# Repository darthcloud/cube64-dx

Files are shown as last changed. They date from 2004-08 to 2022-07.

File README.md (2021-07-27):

See my new project:\
BlueRetro - Multiplayer Bluetooth controllers adapter for retro video game consoles\
<https://hackaday.io/project/170365-blueretro>\
<https://github.com/darthcloud/BlueRetro>

# Cube64

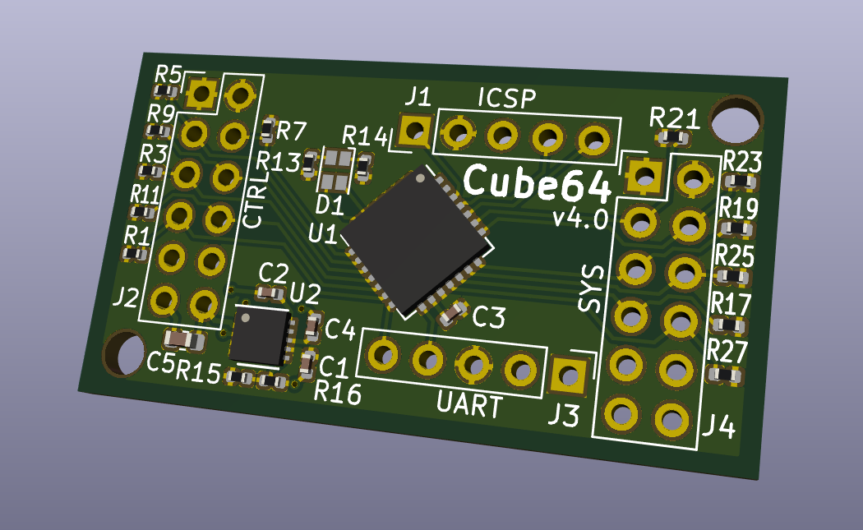
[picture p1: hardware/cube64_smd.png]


## Introduction
This is a project to build an adaptor for using GameCube controllers
with N64 consoles. The motivation behind this is that the N64 has some
really great games, but the controller hardware is rather bad- the
joysticks wear out quickly, and the layout is odd. The GameCube
controllers, however, have a superset of the features and a much
better joystick.

A secondary goal of this project is to more thoroughly reverse engineer
the protocols involved and create reusable libraries for interfacing PIC
microcontrollers to N64 and GameCube devices. The very basics of reverse
engineering the two protocols were done before Micah (@scanlime) started this project,
but she quickly discovered that there's much more to the protocol. We believe
this project may be the first one to completely reverse engineer the
protocol used by standard N64 controllers, including peripherals like the
Controller and Rumble Paks.

All code here is released under the GPL. This means that if you have basic
electronics skills and a way to program the microcontroller, you can build
your own cube64 adaptor easily. The hardware is extremely simple, and all
the complexity of reverse engineering and writing code is done for you ;)

## Discussion

https://github.com/darthcloud/cube64-dx/discussions

## Usage

The completed adaptor plugs into an N64 console, and a regular GameCube
controller or WaveBird receiver plugs into the adaptor.
The default button mapping is as follows:

GameCube | N64
-------- | ---
 | 
 | 
 | 
 | 
 | 
 | 
 | 
 | 
 | 
 | 
 | 

By default the adaptor layout banks are loaded with the first four preset.
See [wiki](https://github.com/darthcloud/cube64-dx/wiki) for more information on the preset.

### Main menu

All the configurable feature of the adaptor can be accessed thought this menu.
To access the menu:

   1. Hold down the analog L and R buttons down most of the way, but not enough to
      push the end-stop buttons, and press Start.

The adaptor LED will be ON as long you are inside the menu.

Once in the menu the N64 will receive blank status packet regardless of buttons
pressed on the GameCube controller. An invalid selection in the menu will exit
the menu.

### Menu options

#### Axis & Button remapping

The button mapping is stored in non-volatile memory, and may be modified during
gameplay. To change the mapping for one button or axis direction:

  1. While in the main menu, press Start again.

  2. If you have the rumble power connected, you should feel a brief rumble.

  3. Press the button you wish to remap. This includes any button or axis direction.

  4. Press the button you want to map it to. This button is always interpreted
     according to the table below.

  5. If the mapping was successful and you have rumble power connected, you should feel
     a brief rumble.

GameCube | N64
-------- | ---
 | 
 | 
 | 
 | 
 | 
 | 
 | 
 | 
 | 
 | 
 | 

#### Special function

It's possible to map a special function to a button instead of a N64 button.

  1. While in the main menu, press Y.

  2. If you have the rumble power connected, you should feel a brief rumble.

  3. Press the button you wish to set the function to.

  4. If you have the rumble power connected, you should feel a brief rumble.

  5. Press the button corresponding to the special function you want. This button is always
     interpreted according to the defaults below.

  6. If the mapping was successful and you have rumble power connected, you should feel
     a brief rumble.

##### Function available:

GameCube | Function
-------- | --------
 | Temporary overwrite current mapping layout <br/>with layout corresponding to the D-pad <br/>direction until button is released.
 | A+C-Down two buttons mapping.
 | B+C-Right two buttons mapping.
 | Turbo disable (Default).
 | Faster turbo.
 | Medium turbo.
 | Slower turbo.

#### Mapping analog trigger axes

By default button remapping and special function will only map to the digital trigger buttons.
Pressing X before either menu options will allow mapping to the analog trigger axes.

  1. While in the main menu, press X.

  2. If you have the rumble power connected, you should feel a brief rumble.

  3. Press either Start or Y. See *Axis & Button remapping* or *Special function* sections for next steps.

#### Mapping layout reset

To reset the current active mapping layout to the above defaults:

  1. While in the main menu, press Z.

  2. If you have the rumble power connected and the reset was successful, you should
     feel a brief rumble.

#### Adaptor accessory mode

The adaptor can either emulate a Rumble Pak, let all controller slot command
bypass to a real N64 controller or display the slot as empty.
To switch between the modes:

  1. While in the main menu, press D-pad UP.

  2. If you have the rumble power connected, you should feel a brief rumble.

  3. Press D-pad UP for bypass mode, D-pad LEFT for Rumble Pak mode or D-pad RIGHT
     for emptied slot controller.

  4. If you have the rumble power connected and the mode change was successful, you should
     feel a brief rumble.

This setting is volatile. Adaptor always starts with Rumble Pak mode.

Empty mode is useful for some game that report error with a Rumble Pak.
For those games, without even invoking the main menu you may simply hold D-pad RIGHT
on power on to disable the Rumble Pak mode and avoid the error.

Holding D-pad UP at boot will set bypass mode as well.

Setting bypass mode while no N64 controller is present in the secondary adaptor port will make
the adaptor reset.

#### Mapping layout selection

It is possible to save up to 4 sets of mapping layouts so you can easily use different keys
mapping in different games. To change between the layout does the following:

  1. While in the main menu, press D-pad LEFT.

  2. If you have the rumble power connected, you should feel a brief rumble.

  3. Press one of the 4 D-pad directions which correspond to the 4 layout available.

  4. If you have the rumble power connected and the layout change was successful, you should
     feel a brief rumble.

All layout by default hold the default button configuration. Just select one of 4
layouts and then change the button configuration using the button mapping key combo
described above.

When you select a layout, it is saved into the EEPROM so the next time you power up
the adaptor the last used will be reloaded automatically.

#### GameCube joysticks config

By default the joysticks value from the GameCube controller are scale to match the N64
joystick value range. This can be disabled to use the GameCube range instead (< v3.1 behavior).
A response curve can also be applied to a GC axis. By default none is applied (Linear).
Scale and curve setting are save independently for each axis and each layout.

  1. While in the main menu, press D-pad RIGHT.

  2. If you have the rumble power connected, you should feel a brief rumble.

  3. Press either direction on one of the four GC joystick axes.

  4. If you have the rumble power connected, you should feel a brief rumble.

  5. Press X to enable or Y to disable the scaling function.
     Or press one of the D-pad directions for enabling a response curve.
     (UP: Aggressive, LEFT: Relaxed, RIGHT: Wide, DOWN: S-Curve)
     Or press A for no response curve (Linear).

  6. If you have the rumble power connected and the layout change was successful, you should
     feel a brief rumble.

This option is saved into the EEPROM so the next time you power up the adaptor the last
used setting will be reloaded automatically.

#### Preconfigured button mapping layout

Eight pre-defined button mapping layout can be loaded in the currently active layout.
See [wiki](https://github.com/darthcloud/cube64-dx/wiki) for preset detail.

  1. While in the main menu, press D-pad DOWN.

  2. If you have the rumble power connected, you should feel a brief rumble.

  3. Press any direction on GC D-pad or main joystick to choose one preset.

  4. If you have the rumble power connected, you should feel a brief rumble.

### Calibration

The adaptor handles calibration in almost the exact same way a GameCube does. If
your joystick is drifting or unresponsive during gameplay, you should be able to
recalibrate it by performing any of the following actions without touching the
joystick, C-stick, L button, or R button:

  1. Hold down X, Y, and Start for a couple seconds during gameplay.

  2. Unplug the controller from the adaptor and plug it back in.

  3. Unplug the adaptor from the N64 and plug it back in.

  4. Turn off the N64 then turn it back on. (The reset button won't
     recalibrate, since the adaptor doesn't lose power or get reinitialized)

### 1 player 2 controllers control style

If connected to two ports of the system, the adaptor will answer automatically
a limited button status and identity commands on the 2nd port. This allows
to play GoldenEye 007 and Perfect Dark using their respective 1 player 2 controller
control style.

Analog input map for the 1st controller C Buttons will map to the 2nd controller joystick.
Digital input map for the 1st controller R button will map to the 2nd controller Z button.

## Hardware

There are currently two versions of the Cube64 hardware:

  - The "Cube64 DIY" uses a PIC18F14K22 microcontroller. Just about any
    electronics hobbyist should be able to build it easily. 5V can be
    provided either externally or by using a charge pump in 8-pin SOIC
    package.

  - The "Cube64 SMD" uses a PIC18F24Q10 microcontroller, and a
    charge pump in 10-pin DFN package. PCB gerber and KiCad sources
    are provided.

Both versions of the hardware have the same button remapping features
and responsiveness, as the only difference in their firmware is a few lines
worth of compile-time configuration. The DIP version of the Q10 could also
be used for the DIY version, but the package is bigger.

## Status

The protocol used between the N64 and controller, and between the controller
and Controller Pak is well understood now. An RS-232 to N64 bridge and several
Python programs demonstrate just about all of the protocol.

The necessary subset of the protocol has been implemented in the Cube64
firmware to emulate an official N64 controller with Rumble Pak. If 5V power
for the motor can be supplied to the GameCube controller, its rumble motor
will be used to emulate the N64 Rumble Pak.

It should be possible to emulate the N64 Controller Pak using the results of the
reverse engineering.

## Contents

##### firmware
Source code for the firmware, in PIC assembly. It was developed
using the open source "gputils" package (use latest [snapshot](https://sourceforge.net/projects/gputils/files/snapshot_builds/src/)). The firmware for
the adaptor itself is "cube64.asm", but there are a few additional
test programs and libraries.

##### hardware
This includes schematics and PCB for the adaptor, in KiCad source format.

##### notes
Utilities and documentation produced while reverse engineering.

## Authors
* **Micah Elizabeth Scott** - *Initial version* - [scanlime](https://github.com/scanlime)
* **Jacques Gagnon** - *Newer stuff* - [DarthCloud](https://github.com/darthcloud)

## References
* <http://www.int03.co.uk/crema/hardware/gamecube/gc-control.htm>
* <http://hitmen.c02.at/files/yagcd/yagcd/chap9.html>
* [http://instruct1.cit.cornell.edu/courses/ee476/FinalProjects/s2002/jew17/lld.html](https://web.archive.org/web/20130607051924/http://instruct1.cit.cornell.edu/courses/ee476/FinalProjects/s2002/jew17/lld.html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)
* [http://www.mixdown.ca/n64dev/](https://web.archive.org/web/20101230015154/http://www.mixdown.ca:80/n64dev/)

## External links
* [Original repository archive](https://github.com/scanlime/navi-misc/tree/master/wasabi/devices/cube64)
* [Google Code repository archive](https://code.google.com/archive/p/cube64-dx/)
* [Blog post](http://scanlime.org/2011/03/cube64-gamecube-to-n64-adaptor/)

## Buttons graphic sources
* N64: [Toomai](https://www.ssbwiki.com/User:Toomai) @[ssbwiki.com](https://www.ssbwiki.com/User:Toomai/SVG_test_page)
* GC: [Flark](https://wiibrew.org/wiki/User:Flark) & [Crayon](https://wiibrew.org/wiki/User:Crayon) @[wiibrew.org](https://wiibrew.org/wiki/Category:Controller_Buttons)
* SVGs: Clone https://github.com/darthcloud/cube64-dx.wiki.git

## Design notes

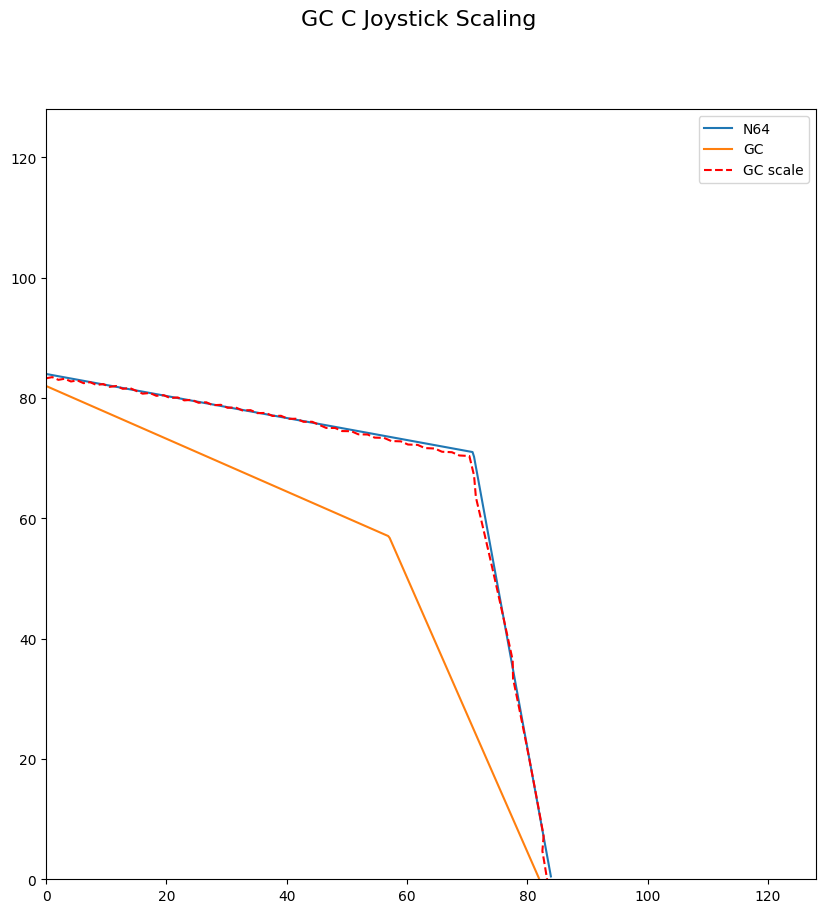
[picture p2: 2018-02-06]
notes/figure/gc_c_scaling.png

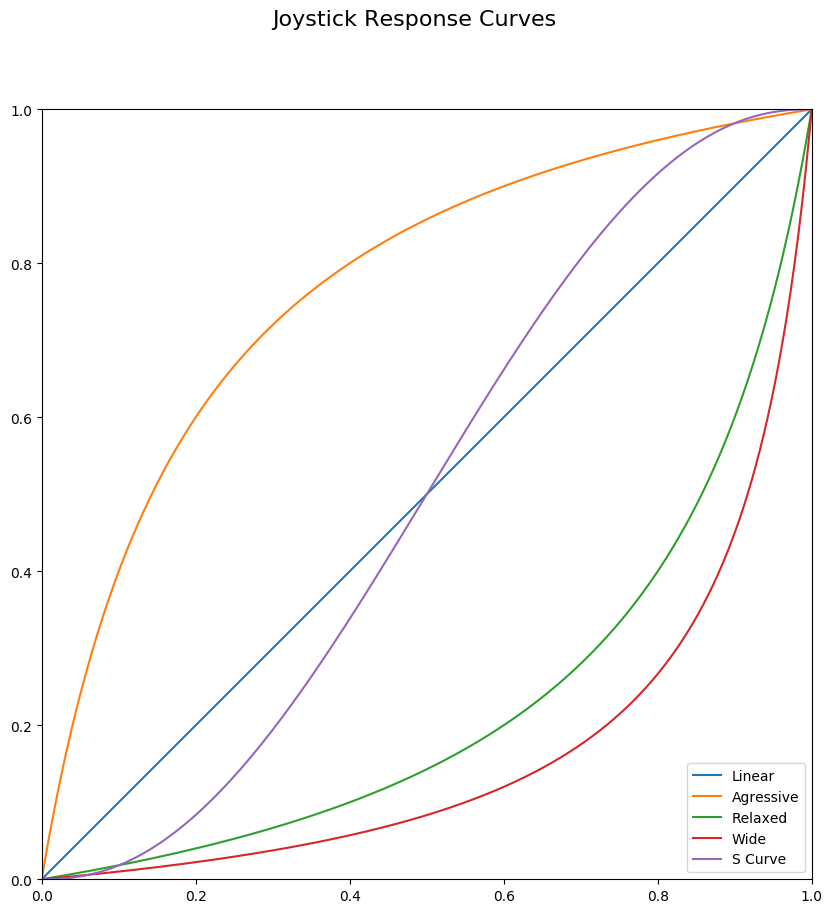
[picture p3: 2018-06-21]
notes/figure/js_response_curves.png

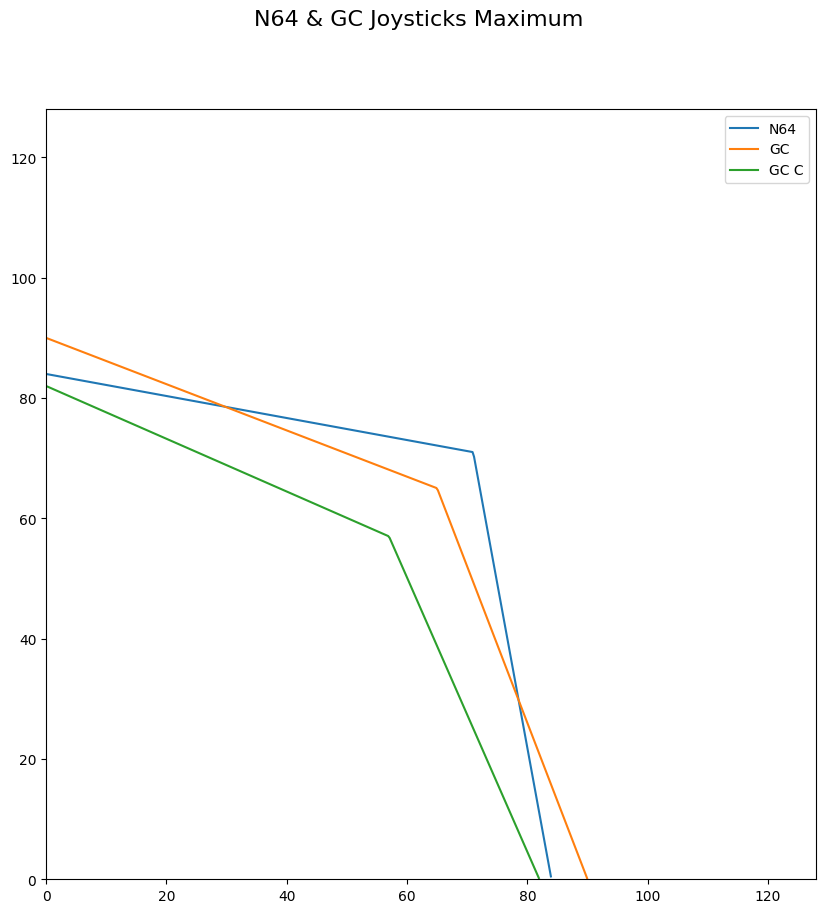
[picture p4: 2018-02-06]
notes/figure/n64_gc_joysticks_max.png

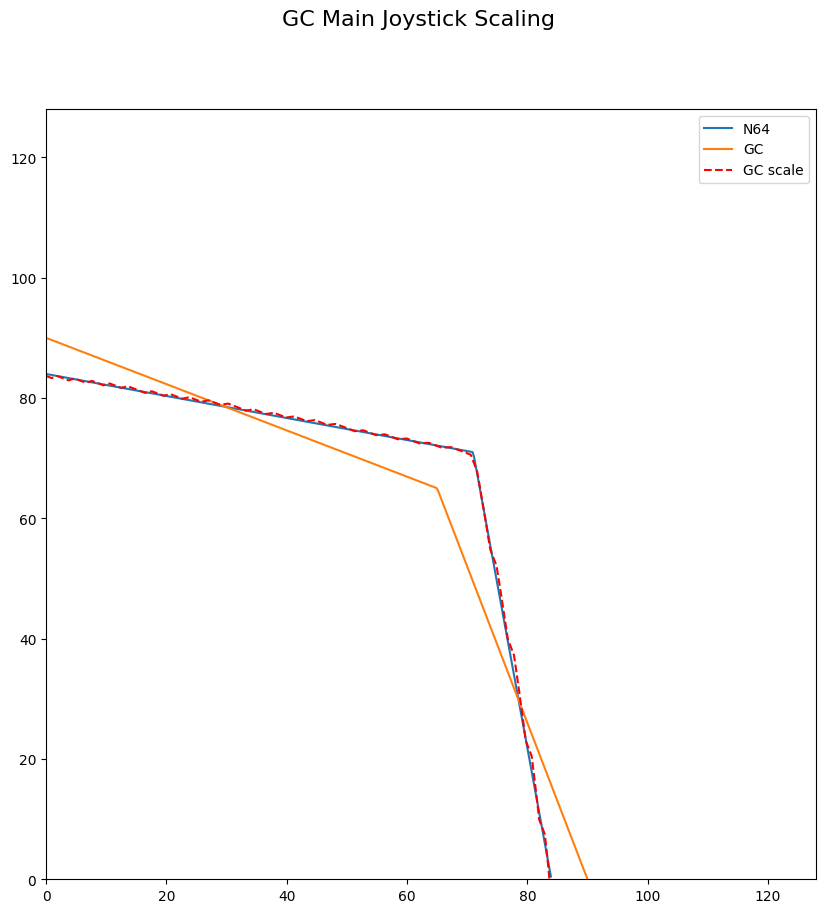
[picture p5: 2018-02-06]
notes/figure/gc_main_scaling.png

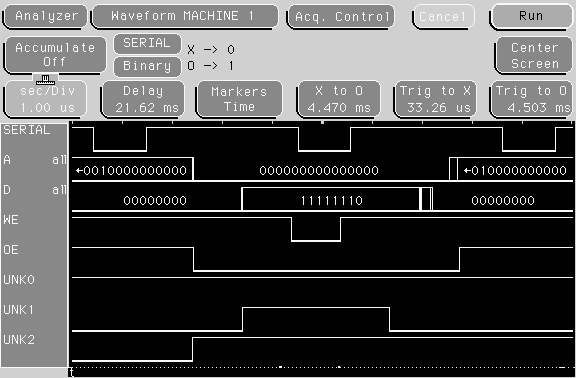
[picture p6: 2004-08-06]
notes/analyzer/wr1_s2.png

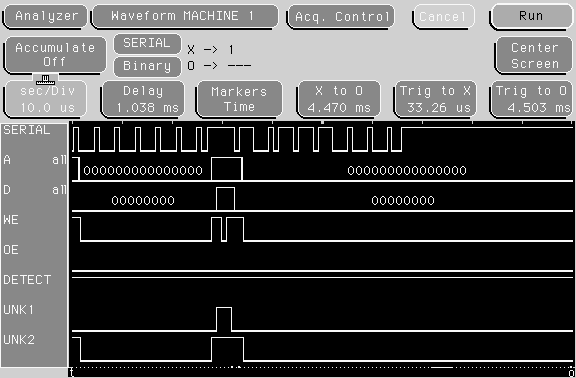
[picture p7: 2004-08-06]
notes/analyzer/no_pak.png

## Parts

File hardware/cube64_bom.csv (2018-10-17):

Component | Description | Part | References | Value | Footprint | Quantity Per PCB | Datasheet | Digikey Part
1 | Unpolarized capacitor | C | C3 | 0.1u | C_0402_1005Metric | 1 | ~ | 1276-1004-1-ND
2 | Unpolarized capacitor | C | C1 C2 C4 | 2.2u | C_0402_1005Metric | 3 | ~ | 1276-1888-1-ND
3 | Unpolarized capacitor | C | C5 | 4.7u | C_0603_1608Metric | 1 | ~ | 1276-1907-1-ND
4 | LED dual, 4-pin | LED_Dual_AACC | D1 | LTST-C195KGJRKT | D_0606_1616Metric | 1 | https://media.digikey.com/pdf/Data%20Sheets/Lite-On%20PDFs/LTST-C195KGJRKT.pdf | 160-1452-1-ND
5 | Resistor US symbol | R | R16 | 100K | R_0402_1005Metric | 1 | ~ | RMCF0402JT100KCT-ND
6 | Resistor US symbol | R | R3 R9 | 1K | R_0402_1005Metric | 2 | ~ | 311-1.0KJRCT-ND
7 | Resistor US symbol | R | R15 | 402K | R_0402_1005Metric | 1 | ~ | YAG3151CT-ND
8 | Resistor US symbol | R | R13 R14 | 64.9 | R_0402_1005Metric | 2 | ~ | RMCF0402FT64R9CT-ND
9 |  | LTC3203B-1 | U2 | LTC3203B-1 | DFN-10-1EP_3x3mm_P0.5mm_EP1.55x2.48mm | 1 | http://www.linear.com/docs/15197 | LTC3203BEDD-1#PBF-ND
10 |  | PIC18F24Q10 | U1 | PIC18F24Q10 | QFN-28-1EP_6x6mm_P0.65mm_EP4.25x4.25mm_ThermalVias | 1 | http://www.microchip.com/mymicrochip/filehandler.aspx?ddocname=en601194 | PIC18F24Q10-I/ML-ND
Component Groups: | 13
Component Count: | 40
Fitted Components: | 14
Number of PCBs: | 1
Total components: | 14
Schematic Version: | A
Schematic Date: | 2018-10-10
BoM Date: | Wed 10 Oct 2018 10:24:46 PM EDT
Schematic Source: | cube64-dx/hardware/cube64.sch
KiCad Version: | Eeschema 5.0.0-fee4fd1~66~ubuntu18.04.1

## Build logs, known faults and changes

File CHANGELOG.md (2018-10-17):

# Changelog

## [4.0] - 2018-10-17
### Added
 - Kicad PCB design gerber/sources.
 - PIC18F24Q10 support.

### Changed
 - Makefile now use PICKIT4 and IPECMD
 - Schematic now in KiCad format.

## [3.5] - 2018-10-06
### Added
 - Pre-defined button layout.
 - Two buttons special mapping options for A+C-Down and B+C-Left.
 - Turbo buttons special feature.

### Changed
 - Serial bridge ported to PIC18F14K22.

## [3.4] - 2018-06-21
### Added
 - Joystick response curve per axis and layout.
 - Menu LED indicator.

### Changed
 - Answer N64 poll within WaveBird init.
 - Mute joysticks input while in menu.

## [3.3] - 2018-06-05
### Added
 - Interrupt based reply.
 - Support 1 player 2 controllers control style.

## [3.2] - 2018-06-01
### Changed
 - N64 controller pin on PORTB.
 - Joystick scaling menu option.

## [3.1] - 2018-02-05
### Added
 - Slot bypass mode. (Fixes #10)
 - GameCube joysticks scaling. (Fixes #7)

### Changed
 - Ported Python2 scripts to Python3.

## [3.0] - 2018-01-03
### Added
 - Support PIC18F14K22 microcontroller.
 - Real-time CRC calculation. (Fixed issue #1)
 - Axes remapping.
 - Layout modifier function.

### Changed
 - Configuration menu.
 - EEPROM flexibility.

### Removed
 - Support PIC12F683 microcontroller.

## [2.0] - 2011-04-20
### Added
 - Support PIC12F683 microcontroller.
 - Support identify command 0xFF. (Fixed issue #2)
 - Enable/Disable Rumple Pak emulation. (Enhancement #4)
 - Support WaveBird. (Enhancement #5)
 - Support 4 mapping layout.

### Removed
 - Support for PIC16F84A & PIC12F629.

## [1.0] - 2004-08-07
 - Initial version.

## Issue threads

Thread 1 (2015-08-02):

Rumple pak emulation bug in some games

GoogleCodeExporter, 2015-08-02:
```
Bug #1: The rumble pak emulation didn't work.
Bug #2: This bug is realy weird. When I use the adapter with that game, the game
            sometime like every 5 or 10 seconde had I little
framerate down, you can easyly
            see that just be watching the opening demo of the game.
It's not a big lag but
            enough to notice it with the picture and the sound (sound
cut). If I unplug the
            adapter everything go back to normal.
```

Original issue reported on code.google.com by `DarthCloud@gmail.com` on 26 Mar 2011 at 7:23

Closed 2018-01-04.

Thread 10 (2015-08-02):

[Feature] Memory Card Pass-through

GoogleCodeExporter, 2015-08-02:
```
I have built several Cube-64DX’s and am very happy with them! Thank you for
all your hard work updating the Cube64 to support Wavebirds. I am currently
building a custom N64 with the controller ports replaced by Camecube ports.
(Allowing direct connection of Wavebirds and GC controllers.)

The problem I am going to have is regarding memory cars (Controller Pak’s).
As I will not have actual N64 ports available, I will not be able to swap out
the Wavebirds for N64 controllers when I need to save/load some games. I
understand that in order for the chip to emulate a memory card it would require
quite a bit more work.

My proposal is this: Pass-through all traffic for the memory card out to a
physical ‘Nintendo Controller Pak’ without processing through the PIC,
attached to the PIC with leads. This way I could mount a memory card inside the
case of the N64 and use it for the few games I would need it for. The other
benefit would be someone could add a memory card port to their Cube64-DX and
swap out memory cars just like an original N64 controller.

I have plenty of working N64 controllers and Controller Pak’s that I would
happily destroy in an effort to accomplish this.

Is something like this possible?
```

Original issue reported on code.google.com by `tim....@gmail.com` on 4 Nov 2011 at 4:48

Closed 2018-02-06.

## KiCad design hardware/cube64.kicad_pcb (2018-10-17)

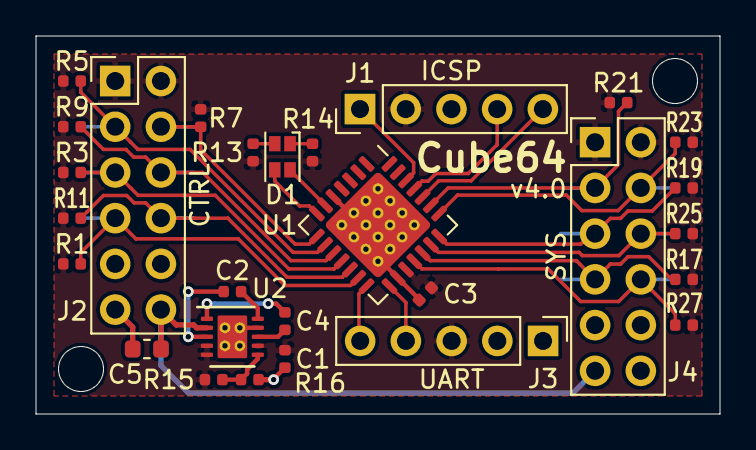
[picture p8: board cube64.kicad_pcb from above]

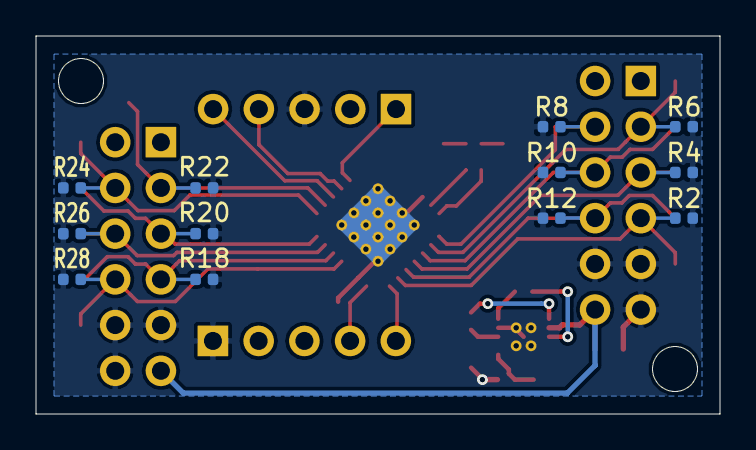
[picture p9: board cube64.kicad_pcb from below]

Board: 2 copper layers, 38.0 x 21.0 mm, 40 parts (12 on the bottom side), 29 nets.

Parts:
C1, C2, C4: 2.2u; C_0402_1005Metric
C3: 0.1u; C_0402_1005Metric
C5: 4.7u; C_0603_1608Metric
D1: LED_Dual_AACC; D_0606_1616Metric
J1: ICSP; PinHeader_1x05_P2.54mm_Vertical
J2: CTRL; PinHeader_2x06_P2.54mm_Vertical
J3: UART; PinHeader_1x05_P2.54mm_Vertical
J4: SYS; PinHeader_2x06_P2.54mm_Vertical
R1, R2, R4, R5, R6, R7, R8, R10, R11, R12, R17, R18, R19, R20, R21, R22, R23, R24, R25, R26, R27, R28: DNP; R_0402_1005Metric
R3, R9: 1K; R_0402_1005Metric
R13, R14: 64.9; R_0402_1005Metric
R15: 402K; R_0402_1005Metric
R16: 100K; R_0402_1005Metric
U1: PIC18F24Q10; QFN-28-1EP_6x6mm_P0.65mm_EP4.25x4.25mm_ThermalVias
U2: LTC3203B-1; DFN-10-1EP_3x3mm_P0.5mm_EP1.55x2.48mm

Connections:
+3V3: C1.1, C3.1, J1.2, J2.1, J2.2, J3.3, J4.1, J4.2, R1.1, R3.1, R5.1, R7.1, R9.1, R11.1, R13.1, R14.1, R15.1, R17.1, R19.1, R21.1, R23.1, R25.1, R27.1, U1.17, U2.4, U2.5, U2.7
+5V: C5.1, J2.12, J4.11, U2.2
/CTRL0: J2.4, R7.2, R8.1, U1.8
/CTRL1: J2.3, R5.2, R6.1, U1.9
/CTRL2: J2.6, R9.2, R10.1, U1.10
/CTRL3: J2.5, R3.2, R4.1, U1.11
/CTRL4: J2.8, R11.2, R12.1, U1.12
/CTRL5: J2.7, R1.2, R2.1, U1.13
/G_LED: D1.3, U1.6
/PGC: J1.5, U1.24
/PGD: J1.4, U1.25
/R_LED: D1.4, U1.7
/SYS0: J4.3, R21.2, R22.1, U1.23
/SYS1: J4.4, R23.2, R24.1, U1.22
/SYS2: J4.5, R19.2, R20.1, U1.21
/SYS3: J4.6, R25.2, R26.1, U1.20
/SYS4: J4.7, R17.2, R18.1, U1.19
/SYS5: J4.8, R27.2, R28.1, U1.18
/UART_RX: J3.4, U1.15
/UART_TX: J3.5, U1.14
GND: C1.2, C3.2, C5.2, J1.3, J2.9, J2.10, J2.11, J3.1, J4.9, J4.10, J4.12, R2.2, R4.2, R6.2, R8.2, R10.2, R12.2, R16.2, R18.2, R20.2, R22.2, R24.2, R26.2, R28.2, U1.5, U1.16, U1.29, U2.9, U2.11
unnamed: C2.1, U2.3
unnamed: C2.2, U2.10
unnamed: C4.1, U2.1
unnamed: C4.2, U2.8
unnamed: D1.1, R14.2
unnamed: D1.2, R13.2
unnamed: R15.2, R16.1, U2.6
VPP: J1.1, U1.26

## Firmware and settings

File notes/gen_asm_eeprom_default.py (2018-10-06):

#!/usr/bin/env python3
#
# This script generate the default buttons mapping layout file.
#
# --Jacques Gagnon <darthcloud@gmail.com>
#

import sys, os
from enum import IntEnum, auto

class ProperEnum(IntEnum):
    def _generate_next_value_(name, start, count, last_values):
        return count

class buttons(ProperEnum):
    BTN_D_UP = auto()
    BTN_D_LEFT = auto()
    BTN_D_RIGHT = auto()
    BTN_D_DOWN = auto()
    BTN_LJ_UP = auto()
    BTN_LJ_LEFT = auto()
    BTN_LJ_RIGHT = auto()
    BTN_LJ_DOWN = auto()
    BTN_RJ_UP = auto()
    BTN_RJ_LEFT = auto()
    BTN_RJ_RIGHT = auto()
    BTN_RJ_DOWN = auto()

    BTN_LA = auto()
    BTN_L = auto()
    BTN_RA = auto()
    BTN_R = auto()
    BTN_LZ = auto()
    BTN_LG = auto()
    BTN_LJ = auto()
    BTN_RZ = auto()
    BTN_RG = auto()
    BTN_RJ = auto()

    BTN_A = auto()
    BTN_B = auto()
    BTN_X = auto()
    BTN_Y = auto()

    BTN_SELECT = auto()
    BTN_HOME = auto()
    BTN_START = auto()
    BTN_C = auto()
    BTN_NONE = auto()
    BTN_A_C_DOWN = 0x36
    BTN_B_C_LEFT = 0x37

        #Default Value       #Button Address
buttons_presets = [
    [   #0: Default (Z on L)
        buttons.BTN_D_UP,    #BTN_D_UP
        buttons.BTN_D_LEFT,  #BTN_D_LEFT
        buttons.BTN_D_RIGHT, #BTN_D_RIGHT
        buttons.BTN_D_DOWN,  #BTN_D_DOWN
        buttons.BTN_LJ_UP,   #BTN_LJ_UP
        buttons.BTN_LJ_LEFT, #BTN_LJ_LEFT
        buttons.BTN_LJ_RIGHT,#BTN_LJ_RIGHT
        buttons.BTN_LJ_DOWN, #BTN_LJ_DOWN
        buttons.BTN_RJ_UP,   #BTN_RJ_UP
        buttons.BTN_RJ_LEFT, #BTN_RJ_LEFT
        buttons.BTN_RJ_RIGHT,#BTN_RJ_RIGHT
        buttons.BTN_RJ_DOWN, #BTN_RJ_DOWN

        buttons.BTN_NONE,    #BTN_LA
        buttons.BTN_RZ,      #BTN_L
        buttons.BTN_NONE,    #BTN_RA
        buttons.BTN_R,       #BTN_R
        buttons.BTN_NONE,    #BTN_LZ
        buttons.BTN_NONE,    #BTN_LG
        buttons.BTN_NONE,    #BTN_LJ
        buttons.BTN_RJ_RIGHT,#BTN_RZ
        buttons.BTN_NONE,    #BTN_RG
        buttons.BTN_NONE,    #BTN_RJ

        buttons.BTN_A,       #BTN_A
        buttons.BTN_B,       #BTN_B
        buttons.BTN_RJ_DOWN, #BTN_X
        buttons.BTN_RJ_LEFT, #BTN_Y

        buttons.BTN_NONE,    #BTN_SELECT
        buttons.BTN_NONE,    #BTN_HOME
        buttons.BTN_START,   #BTN_START
        buttons.BTN_NONE,    #BTN_C
        0x00,                #JS_CURVE
        0x00,                #CS_CURVE
    ],
    [   #1: Modern FPS (Z on R, Joystick/C-buttons swap)
        buttons.BTN_D_UP,    #BTN_D_UP
        buttons.BTN_D_LEFT,  #BTN_D_LEFT
        buttons.BTN_D_RIGHT, #BTN_D_RIGHT
        buttons.BTN_D_DOWN,  #BTN_D_DOWN
        buttons.BTN_RJ_UP,   #BTN_LJ_UP
        buttons.BTN_RJ_LEFT, #BTN_LJ_LEFT
        buttons.BTN_RJ_RIGHT,#BTN_LJ_RIGHT
        buttons.BTN_RJ_DOWN, #BTN_LJ_DOWN
        buttons.BTN_LJ_UP,   #BTN_RJ_UP
        buttons.BTN_LJ_LEFT, #BTN_RJ_LEFT
        buttons.BTN_LJ_RIGHT,#BTN_RJ_RIGHT
        buttons.BTN_LJ_DOWN, #BTN_RJ_DOWN

        buttons.BTN_NONE,    #BTN_LA
        buttons.BTN_R,       #BTN_L
        buttons.BTN_NONE,    #BTN_RA
        buttons.BTN_RZ,      #BTN_R
        buttons.BTN_NONE,    #BTN_LZ
        buttons.BTN_NONE,    #BTN_LG
        buttons.BTN_NONE,    #BTN_LJ
        buttons.BTN_L,       #BTN_RZ
        buttons.BTN_NONE,    #BTN_RG
        buttons.BTN_NONE,    #BTN_RJ

        buttons.BTN_A,       #BTN_A
        buttons.BTN_B,       #BTN_B
        buttons.BTN_D_DOWN,  #BTN_X
        buttons.BTN_D_UP,    #BTN_Y

        buttons.BTN_NONE,    #BTN_SELECT
        buttons.BTN_NONE,    #BTN_HOME
        buttons.BTN_START,   #BTN_START
        buttons.BTN_NONE,    #BTN_C
        0x00,                #JS_CURVE
        0x00,                #CS_CURVE
    ],
    [   #2: 3rd Person shooter / Legacy FPS (Z on R)
        buttons.BTN_D_UP,    #BTN_D_UP
        buttons.BTN_D_LEFT,  #BTN_D_LEFT
        buttons.BTN_D_RIGHT, #BTN_D_RIGHT
        buttons.BTN_D_DOWN,  #BTN_D_DOWN
        buttons.BTN_LJ_UP,   #BTN_LJ_UP
        buttons.BTN_LJ_LEFT, #BTN_LJ_LEFT
        buttons.BTN_LJ_RIGHT,#BTN_LJ_RIGHT
        buttons.BTN_LJ_DOWN, #BTN_LJ_DOWN
        buttons.BTN_RJ_UP,   #BTN_RJ_UP
        buttons.BTN_RJ_LEFT, #BTN_RJ_LEFT
        buttons.BTN_RJ_RIGHT,#BTN_RJ_RIGHT
        buttons.BTN_RJ_DOWN, #BTN_RJ_DOWN

        buttons.BTN_NONE,    #BTN_LA
        buttons.BTN_R,       #BTN_L
        buttons.BTN_NONE,    #BTN_RA
        buttons.BTN_RZ,      #BTN_R
        buttons.BTN_NONE,    #BTN_LZ
        buttons.BTN_NONE,    #BTN_LG
        buttons.BTN_NONE,    #BTN_LJ
        buttons.BTN_L,       #BTN_RZ
        buttons.BTN_NONE,    #BTN_RG
        buttons.BTN_NONE,    #BTN_RJ

        buttons.BTN_A,       #BTN_A
        buttons.BTN_B,       #BTN_B
        buttons.BTN_RJ_DOWN, #BTN_X
        buttons.BTN_RJ_LEFT, #BTN_Y

        buttons.BTN_NONE,    #BTN_SELECT
        buttons.BTN_NONE,    #BTN_HOME
        buttons.BTN_START,   #BTN_START
        buttons.BTN_NONE,    #BTN_C
        0x00,                #JS_CURVE
        0x00,                #CS_CURVE
    ],
    [   #3: Racing (JS Up/Down on Analog R/L)
        buttons.BTN_D_UP,    #BTN_D_UP
        buttons.BTN_D_LEFT,  #BTN_D_LEFT
        buttons.BTN_D_RIGHT, #BTN_D_RIGHT
        buttons.BTN_D_DOWN,  #BTN_D_DOWN
        buttons.BTN_NONE,    #BTN_LJ_UP
        buttons.BTN_LJ_LEFT, #BTN_LJ_LEFT
        buttons.BTN_LJ_RIGHT,#BTN_LJ_RIGHT
        buttons.BTN_NONE,    #BTN_LJ_DOWN
        buttons.BTN_RJ_UP,   #BTN_RJ_UP
        buttons.BTN_RJ_LEFT, #BTN_RJ_LEFT
        buttons.BTN_RJ_RIGHT,#BTN_RJ_RIGHT
        buttons.BTN_RJ_DOWN, #BTN_RJ_DOWN

        buttons.BTN_LJ_DOWN, #BTN_LA
        buttons.BTN_NONE,    #BTN_L
        buttons.BTN_LJ_UP,   #BTN_RA
        buttons.BTN_NONE,    #BTN_R
        buttons.BTN_NONE,    #BTN_LZ
        buttons.BTN_NONE,    #BTN_LG
        buttons.BTN_NONE,    #BTN_LJ
        buttons.BTN_RJ_RIGHT,#BTN_RZ
        buttons.BTN_NONE,    #BTN_RG
        buttons.BTN_NONE,    #BTN_RJ

        buttons.BTN_A,       #BTN_A
        buttons.BTN_B,       #BTN_B
        buttons.BTN_D_DOWN,  #BTN_X
        buttons.BTN_D_UP,    #BTN_Y

        buttons.BTN_NONE,    #BTN_SELECT
        buttons.BTN_NONE,    #BTN_HOME
        buttons.BTN_START,   #BTN_START
        buttons.BTN_NONE,    #BTN_C
        0x00,                #JS_CURVE
        0x00,                #CS_CURVE
    ],
    [   #4: Fighting (C-UP/C-DOWN on Z/L/R)
        buttons.BTN_D_UP,    #BTN_D_UP
        buttons.BTN_D_LEFT,  #BTN_D_LEFT
        buttons.BTN_D_RIGHT, #BTN_D_RIGHT
        buttons.BTN_D_DOWN,  #BTN_D_DOWN
        buttons.BTN_LJ_UP,   #BTN_LJ_UP
        buttons.BTN_LJ_LEFT, #BTN_LJ_LEFT
        buttons.BTN_LJ_RIGHT,#BTN_LJ_RIGHT
        buttons.BTN_LJ_DOWN, #BTN_LJ_DOWN
        buttons.BTN_RJ_UP,   #BTN_RJ_UP
        buttons.BTN_RJ_LEFT, #BTN_RJ_LEFT
        buttons.BTN_RJ_RIGHT,#BTN_RJ_RIGHT
        buttons.BTN_RJ_DOWN, #BTN_RJ_DOWN

        buttons.BTN_NONE,    #BTN_LA
        buttons.BTN_RJ_UP,   #BTN_L
        buttons.BTN_NONE,    #BTN_RA
        buttons.BTN_RJ_RIGHT,#BTN_R
        buttons.BTN_NONE,    #BTN_LZ
        buttons.BTN_NONE,    #BTN_LG
        buttons.BTN_NONE,    #BTN_LJ
        buttons.BTN_RZ,      #BTN_RZ
        buttons.BTN_NONE,    #BTN_RG
        buttons.BTN_NONE,    #BTN_RJ

        buttons.BTN_A,       #BTN_A
        buttons.BTN_B,       #BTN_B
        buttons.BTN_RJ_DOWN, #BTN_X
        buttons.BTN_RJ_LEFT, #BTN_Y

        buttons.BTN_NONE,    #BTN_SELECT
        buttons.BTN_NONE,    #BTN_HOME
        buttons.BTN_START,   #BTN_START
        buttons.BTN_NONE,    #BTN_C
        0x00,                #JS_CURVE
        0x00,                #CS_CURVE
    ],
    [   #5: Star Wars: Rogue Squadron (Rogue Leader style)
        buttons.BTN_D_UP,    #BTN_D_UP
        buttons.BTN_D_LEFT,  #BTN_D_LEFT
        buttons.BTN_D_RIGHT, #BTN_D_RIGHT
        buttons.BTN_D_DOWN,  #BTN_D_DOWN
        buttons.BTN_LJ_UP,   #BTN_LJ_UP
        buttons.BTN_LJ_LEFT, #BTN_LJ_LEFT
        buttons.BTN_LJ_RIGHT,#BTN_LJ_RIGHT
        buttons.BTN_LJ_DOWN, #BTN_LJ_DOWN
        buttons.BTN_L,       #BTN_RJ_UP
        buttons.BTN_L,       #BTN_RJ_LEFT
        buttons.BTN_L,       #BTN_RJ_RIGHT
        buttons.BTN_L,       #BTN_RJ_DOWN

        buttons.BTN_RZ,      #BTN_LA
        buttons.BTN_RZ,      #BTN_L
        buttons.BTN_A,       #BTN_RA
        buttons.BTN_RJ_RIGHT,#BTN_R
        buttons.BTN_NONE,    #BTN_LZ
        buttons.BTN_NONE,    #BTN_LG
        buttons.BTN_NONE,    #BTN_LJ
        buttons.BTN_R,       #BTN_RZ
        buttons.BTN_NONE,    #BTN_RG
        buttons.BTN_NONE,    #BTN_RJ

        buttons.BTN_B,       #BTN_A
        buttons.BTN_RJ_LEFT, #BTN_B
        buttons.BTN_RJ_DOWN, #BTN_X
        buttons.BTN_RJ_UP,   #BTN_Y

        buttons.BTN_NONE,    #BTN_SELECT
        buttons.BTN_NONE,    #BTN_HOME
        buttons.BTN_START,   #BTN_START
        buttons.BTN_NONE,    #BTN_C
        0x00,                #JS_CURVE
        0x00,                #CS_CURVE
    ],
    [   #6: Shadows of the Empire (FPS)
        buttons.BTN_D_UP,    #BTN_D_UP
        buttons.BTN_D_LEFT,  #BTN_D_LEFT
        buttons.BTN_D_RIGHT, #BTN_D_RIGHT
        buttons.BTN_D_DOWN,  #BTN_D_DOWN
        buttons.BTN_LJ_UP,   #BTN_LJ_UP
        buttons.BTN_RZ,      #BTN_LJ_LEFT
        buttons.BTN_R,       #BTN_LJ_RIGHT
        buttons.BTN_LJ_DOWN, #BTN_LJ_DOWN
        buttons.BTN_LJ_UP,   #BTN_RJ_UP
        buttons.BTN_LJ_LEFT, #BTN_RJ_LEFT
        buttons.BTN_LJ_RIGHT,#BTN_RJ_RIGHT
        buttons.BTN_LJ_DOWN, #BTN_RJ_DOWN

        buttons.BTN_NONE,    #BTN_LA
        buttons.BTN_RJ_RIGHT,#BTN_L
        buttons.BTN_NONE,    #BTN_RA
        buttons.BTN_A,       #BTN_R
        buttons.BTN_NONE,    #BTN_LZ
        buttons.BTN_NONE,    #BTN_LG
        buttons.BTN_NONE,    #BTN_LJ
        buttons.BTN_RJ_DOWN, #BTN_RZ
        buttons.BTN_NONE,    #BTN_RG
        buttons.BTN_NONE,    #BTN_RJ

        buttons.BTN_B,       #BTN_A
        buttons.BTN_RJ_UP,   #BTN_B
        buttons.BTN_RJ_LEFT, #BTN_X
        buttons.BTN_L,       #BTN_Y

        buttons.BTN_NONE,    #BTN_SELECT
        buttons.BTN_NONE,    #BTN_HOME
        buttons.BTN_START,   #BTN_START
        buttons.BTN_NONE,    #BTN_C
        0x00,                #JS_CURVE
        0x00,                #CS_CURVE
    ],
    [   #7: Tony Hawk (Merged A+C-DOWN & B+C-LEFT)
        buttons.BTN_D_UP,    #BTN_D_UP
        buttons.BTN_D_LEFT,  #BTN_D_LEFT
        buttons.BTN_D_RIGHT, #BTN_D_RIGHT
        buttons.BTN_D_DOWN,  #BTN_D_DOWN
        buttons.BTN_LJ_UP,   #BTN_LJ_UP
        buttons.BTN_LJ_LEFT, #BTN_LJ_LEFT
        buttons.BTN_LJ_RIGHT,#BTN_LJ_RIGHT
        buttons.BTN_LJ_DOWN, #BTN_LJ_DOWN
        buttons.BTN_RJ_UP,   #BTN_RJ_UP
        buttons.BTN_RJ_LEFT, #BTN_RJ_LEFT
        buttons.BTN_RJ_RIGHT,#BTN_RJ_RIGHT
        buttons.BTN_RJ_DOWN, #BTN_RJ_DOWN

        buttons.BTN_NONE,    #BTN_LA
        buttons.BTN_RZ,      #BTN_L
        buttons.BTN_NONE,    #BTN_RA
        buttons.BTN_R,       #BTN_R
        buttons.BTN_NONE,    #BTN_LZ
        buttons.BTN_NONE,    #BTN_LG
        buttons.BTN_NONE,    #BTN_LJ
        buttons.BTN_L,       #BTN_RZ
        buttons.BTN_NONE,    #BTN_RG
        buttons.BTN_NONE,    #BTN_RJ

        buttons.BTN_A_C_DOWN,#BTN_A
        buttons.BTN_B_C_LEFT,#BTN_B
        buttons.BTN_RJ_RIGHT,#BTN_X
        buttons.BTN_RJ_UP,   #BTN_Y

        buttons.BTN_NONE,    #BTN_SELECT
        buttons.BTN_NONE,    #BTN_HOME
        buttons.BTN_START,   #BTN_START
        buttons.BTN_NONE,    #BTN_C
        0x00,                #JS_CURVE
        0x00,                #CS_CURVE
    ],
]

if __name__ == "__main__":
    eeprom_default = "../firmware/eeprom_default.inc"

    if os.path.exists(eeprom_default):
        os.unlink(eeprom_default)

    FILE = open(eeprom_default,"wb")

    FILE.write(b"    ;; EEPROM default data.\n")
    FILE.write(b"    ;; Generated by Jacques Gagnon <darthcloud@gmail.com>.\n")
    FILE.write(b"    ;; See notes/gen_asm_eeprom_default.py\n")
    FILE.write(b"\n")

    for layout in buttons_presets:
        FILE.write(b"    db ")
        for address, default in enumerate(layout):
            FILE.write(b"0x%02X" % default)
            if address < buttons.BTN_NONE+1:
                FILE.write(b", ")
        FILE.write(b"\n")
    FILE.write(b"\n")
    FILE.close()

    print("{} generated.".format(eeprom_default))

### The End ###

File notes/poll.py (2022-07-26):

#!/usr/bin/env python3
#
# Script for polling N64/GC SI bus devices
#
# This script uses the serial bridge and pool in loops
# for the buttons status.
#
# It currently supports N64 controllers, N64 mouses & GameCube controllers.
#
# --Jacques Gagnon <darthcloud@gmail.com>
#

from bus import Bus
from collections import namedtuple, OrderedDict
import struct, time, os, sys

bmap = namedtuple('status', 'name mask color')

identity_req = namedtuple('identity_req', 'cmd')
status_req = namedtuple('status_req', 'cmd')
read_req = namedtuple('read_req', 'cmd address')
write_req = namedtuple('write_req', 'cmd address data')
dol_status_req = namedtuple('dol_status_req', 'cmd unknown rumble')
dol_wb_assoc_req = namedtuple('dol_wb_assoc_req', 'cmd id')

identity_resp = namedtuple('identity_resp', 'id info')
status_resp = namedtuple('status_resp', 'buttons x_axis y_axis')
dol_status_resp = namedtuple('dol_status_resp', 'buttons x_axis y_axis cx_axis cy_axis l_trigger r_trigger')
dol_full_status_resp = namedtuple('dol_full_status_resp', 'buttons x_axis y_axis cx_axis cy_axis l_trigger r_trigger a_press b_press')

RED='\x1b[1;91m'
GREEN='\x1b[1;92m'
YELLOW='\x1b[1;93m'
BLUE='\x1b[1;94m'
MAGENTA='\x1b[1;95m'
CYAN='\x1b[1;96m'
LGRAY='\x1b[1;37m'
DGRAY='\x1b[1;90m'
END='\x1b[0m'

IDENTIFY = 0x00
STATUS = 0x01
READ = 0x02
WRITE = 0x03
DOL_STATUS = 0x40
DOL_FULL_STATUS = 0x43
WB_INIT = 0x4E

MOUSE = 0x02
NUS = 0x05
DOL = 0x09
WB_DOWN = 0xA8
WB_AUTH = 0xE9
WB_ASSOC = 0xEB

EMPTY = 0x00
OCCUPY = 0x01
EMPTIED = 0x02
INSERT = 0x03

BUTTON = {NUS:OrderedDict(
             [('buttons',[bmap('A',0x8000,BLUE),
                          bmap('B',0x4000,GREEN),
                          bmap('Z',0x2000,LGRAY),
                          bmap('St',0x1000,RED),
                          bmap('Up',0x0800,LGRAY),
                          bmap('Dn',0x0400,LGRAY),
                          bmap('Lt',0x0200,LGRAY),
                          bmap('Rt',0x0100,LGRAY),
                          bmap('L',0x0020,LGRAY),
                          bmap('R',0x0010,LGRAY),
                          bmap('CUp',0x0008,YELLOW),
                          bmap('CDn',0x0004,YELLOW),
                          bmap('CLt',0x0002,YELLOW),
                          bmap('CRt',0x0001,YELLOW)]),
              ('x_axis', [bmap('X',0xFF,LGRAY)]),
              ('y_axis', [bmap('Y',0xFF,LGRAY)])]),

          DOL:OrderedDict(
             [('buttons',[bmap('St',0x1000,LGRAY),
                          bmap('Y',0x0800,LGRAY),
                          bmap('X',0x0400,LGRAY),
                          bmap('B',0x0200,RED),
                          bmap('A',0x0100,CYAN),
                          bmap('L',0x0040,LGRAY),
                          bmap('R',0x0020,LGRAY),
                          bmap('Z',0x0010,MAGENTA),
                          bmap('Up',0x0008,LGRAY),
                          bmap('Dn',0x0004,LGRAY),
                          bmap('Rt',0x0002,LGRAY),
                          bmap('Lt',0x0001,LGRAY)]),
              ('x_axis', [bmap('X',0xFF,LGRAY)]),
              ('y_axis', [bmap('Y',0xFF,LGRAY)]),
              ('cx_axis', [bmap('CX',0xFF,YELLOW)]),
              ('cy_axis', [bmap('CY',0xFF,YELLOW)]),
              ('l_trigger', [bmap('AL',0xFF,LGRAY)]),
              ('r_trigger', [bmap('AR',0xFF,LGRAY)]),
              ('a_press', [bmap('A',0xFF,CYAN)]), # A & B pressure only work with DS5 prototype (dev kit) controllers
              ('b_press', [bmap('B',0xFF,RED)]),
              ])}

class Bus(Bus):
    def identify(self):
        reply = self.bridge.write(bytes([IDENTIFY]), 3)[1]

        if reply[0] == MOUSE:
          return {'system':NUS, 'type':'mouse'}
        elif reply[0] == NUS:
          if reply[2] == EMPTY:
            return {'system':NUS, 'type':'controller', 'slot':'Empty  '}
          elif reply[2] == OCCUPY:
            return {'system':NUS, 'type':'controller', 'slot':'Occupy '}
          elif reply[2] == EMPTIED:
            return {'system':NUS, 'type':'controller', 'slot':'Emptied'}
          elif reply[2] == INSERT:
            return {'system':NUS, 'type':'controller', 'slot':'Insert '}
          else:
            print("Unknown N64 controller slot state: {}".format(reply))
            sys.exit()
        elif reply[0] == DOL:
          return {'system':DOL, 'type':'controller'}
        elif reply[0] == WB_DOWN:
          return {'system':WB_DOWN, 'type':'wavebird'}
        elif reply[0] == WB_AUTH:
          return {'system':WB_AUTH, 'type':'wavebird', 'id':reply[-2:]}
        elif reply[0] == WB_ASSOC:
          return {'system':DOL, 'type':'wavebird'}
        else:
          print("Unknown device identity: {}".format(reply))
          sys.exit()

    def status(self, system):
        if system == NUS:
          reply = self.bridge.write(bytes([STATUS]), 4)[1]
          return status_resp._make(struct.unpack('>H2b', reply))
        elif system == DOL:
          reply = self.bridge.write(struct.pack(">BH", DOL_FULL_STATUS, 0x0000), 10)[1]
          return dol_full_status_resp._make(struct.unpack('>H8B', reply))
        else:
          print("Unknown system ID: {}".format(system))
          sys.exit()

    def wavebird_init(self, id):
        return self.bridge.write(struct.pack(">BBB", WB_INIT, (id[0] | 0x20) & 0x10, id[1]), 3)[1]

def poll():
    os.system('setterm -cursor off')

    interface = Bus()
    device = interface.identify()

    time.sleep(0.02)

    while device['system'] == WB_DOWN:
      device = interface.identify()
      time.sleep(1)

    if device['system'] == WB_AUTH:
      interface.wavebird_init(device['id'])

    try:
      while 1:
        device = interface.identify()
        time.sleep(0.02)
        status = interface.status(device['system'])
        for field, values in BUTTON[device['system']].items():
          for value in values:
            if value.mask != 0xFF:
              print("{}{}{} ".format(value.color if getattr(status, field) & value.mask else DGRAY, value.name, END), end='')
            else:
              print("{}{}:{:+03X}{} ".format(value.color, value.name, getattr(status, field), END), end='')
        if 'slot' in device:
          print("slot:{}".format(device['slot']), end='')
        print("\r", end='')
        time.sleep(0.02)
    except KeyboardInterrupt:
      pass

    os.system('setterm -cursor on')
    print("")

if __name__ == "__main__":
    poll()

### The End ###

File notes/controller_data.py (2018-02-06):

#!/usr/bin/env python3
"""Maximum values sampled from various controllers.

 --Jacques Gagnon <darthcloud@gmail.com>
"""

from collections import namedtuple

Point = namedtuple('Point', 'x y')
Origin = namedtuple('Origin', 'up right down left')
Diagonal = namedtuple('Diagonal', 'up_right down_right down_left up_left')
Maximum = namedtuple('Maximum', 'origin diagonal')

CTRL_DATA = {
    # Data sampled directly from N64 controller.
    "N64": [
        # 1996 NUS-005 Launch Controller (Solid Grey)
        # This controller joystick is quite beaten up as you can imagine.
        # Ambiguous bit sent to it (2 us low, 2 us high) are randomly interpreted as either 0 or 1.
        #[
        #    Maximum(
        #        Origin(Point(0, 0x47), Point(0x42, 0), Point(0, -0x50), Point(-0x47, 0)),
        #        Diagonal(Point(0x38, 0x39), Point(0x3c, -0x3f), Point(-0x38, -0x45), Point(-0x41, 0x40))
        #    ),
        #],

        # ~2002 NUS-005 Plastic Packaging Controller (Grape Purple)
        # Joystick is in excellent condition.
        # Older controllers will report controller slot status 0x00 (Empty) at power up.
        # This one report right away 0x02 (Emptied). Cube64 mimic this behavior when disabling
        # rumble emulation at boot up.
        # Ambiguous bit sent to it (2 us low, 2 us high) are always interpreted as 1.
        [
            Maximum(
                Origin(Point(0, 0x57), Point(0x52, 0), Point(0, -0x55), Point(-0x52, 0)),
                Diagonal(Point(0x47, 0x48), Point(0x48, -0x45), Point(-0x43, -0x46), Point(-0x48, 0x49))
            ),
        ],

        # 2003 iQue Controller
        # Brand-new
        # Internally a regular N64 controller. No slot externally.
        #[
        #    Maximum(
        #        Origin(Point(0, 0x53), Point(0x54, 0), Point(0, -0x57), Point(-0x58, 0)),
        #        Diagonal(Point(0x45, 0x42), Point(0x44, -0x44), Point(-0x4a, -0x4a), Point(-0x4a, 0x41))
        #    ),
        #],

        # Horipad Mini 64
        # Brand-new
        # Joystick do not respect regular controller range.
        # The bit period is 6 us!
        #[
        #    Maximum(
        #        Origin(Point(0, 0x57), Point(0x70, 0), Point(0, -0x66), Point(-0x5e, 0)),
        #        Diagonal(Point(0x56, 0x46), Point(0x59, -0x4e), Point(-0x3f, -0x51), Point(-0x41, 0x45))
        #    ),
        #],
    ],

    # Data sampled through the Cube64 adaptor without any scaling.
    # Deadzone and sign was applied.
    "GC": [
        # DOL-003 Controller (Silver)
        # Joystick is in excellent condition.
        [
            Maximum(
                Origin(Point(0, 0x5b), Point(0x5a, 0), Point(0, -0x5b), Point(-0x5b, 0)),
                Diagonal(Point(0x45, 0x43), Point(0x44, -0x41), Point(-0x42, -0x3c), Point(-0x40, 0x42))
            ),
            Maximum(
                Origin(Point(0, 0x53), Point(0x54, 0), Point(0, -0x55), Point(-0x53, 0)),
                Diagonal(Point(0x40, 0x3a), Point(0x3e, -0x3e), Point(-0x3d, -0x37), Point(-0x39, 0x3b))
            ),
        ],

        # DOL-003 Controller SSBB Wii (White)
        # Brand-new.
        [
            Maximum(
                Origin(Point(0, 0x5a), Point(0x59, 0), Point(0, -0x57), Point(-0x53, 0)),
                Diagonal(Point(0x42, 0x41), Point(0x41, -0x46), Point(-0x3a, -0x43), Point(-0x3a, 0x41))
            ),
            Maximum(
                Origin(Point(0, 0x4e), Point(0x51, 0), Point(0, -0x5c), Point(-0x50, 0)),
                Diagonal(Point(0x3b, 0x35), Point(0x3a, -0x44), Point(-0x38, -0x3e), Point(-0x35, 0x36))
            ),
        ],

        # DOL-003 Controller SSBB Wii (White)
        # Brand-new.
        [
            Maximum(
                Origin(Point(0, 0x59), Point(0x55, 0), Point(0, -0x5e), Point(-0x59, 0)),
                Diagonal(Point(0x3c, 0x42), Point(0x3c, -0x46), Point(-0x3f, -0x42), Point(-0x3f, 0x40))
            ),
            Maximum(
                Origin(Point(0, 0x51), Point(0x4c, 0), Point(0, -0x5e), Point(-0x55, 0)),
                Diagonal(Point(0x35, 0x39), Point(0x35, -0x41), Point(-0x3d, -0x3d), Point(-0x3b, 0x39))
            ),
        ],

        # DOL-003 Controller SSB WiiU (White)
        # Brand-new.
        [
            Maximum(
                Origin(Point(0, 0x5d), Point(0x5a, 0), Point(0, -0x5a), Point(-0x59, 0)),
                Diagonal(Point(0x41, 0x43), Point(0x41, -0x3f), Point(-0x41, -0x3c), Point(-0x40, 0x41))
            ),
            Maximum(
                Origin(Point(0, 0x50), Point(0x52, 0), Point(0, -0x5b), Point(-0x57, 0)),
                Diagonal(Point(0x3c, 0x37), Point(0x3b, -0x43), Point(-0x41, -0x3c), Point(-0x3e, 0x37))
            ),
        ],

        # WaveBird Controller (Silver)
        # Joystick is in excellent condition.
        [
            Maximum(
                Origin(Point(0, 0x5f), Point(0x58, 0), Point(0, -0x5d), Point(-0x59, 0)),
                Diagonal(Point(0x3e, 0x43), Point(0x3f, -0x42), Point(-0x3e, -0x40), Point(-0x40, 0x43))
            ),
            Maximum(
                Origin(Point(0, 0x57), Point(0x52, 0), Point(0, -0x4e), Point(-0x4d, 0)),
                Diagonal(Point(0x38, 0x3d), Point(0x38, -0x35), Point(-0x35, -0x36), Point(-0x35, 0x3a))
            ),
        ],

        # WaveBird Controller (Silver)
        # Joystick is in excellent condition.
        [
            Maximum(
                Origin(Point(0, 0x5e), Point(0x57, 0), Point(0, -0x56), Point(-0x5a, 0)),
                Diagonal(Point(0x3c, 0x44), Point(0x3d, -0x3c), Point(-0x4d, -0x3c), Point(-0x43, 0x45))
            ),
            Maximum(
                Origin(Point(0, 0x52), Point(0x4a, 0), Point(0, -0x4e), Point(-0x56, 0)),
                Diagonal(Point(0x32, 0x38), Point(0x33, -0x36), Point(-0x3f, -0x35), Point(-0x3c, 0x39))
            ),
        ],

        # WaveBird Controller (Grey)
        # Joystick is in excellent condition.
        [
            Maximum(
                Origin(Point(0, 0x64), Point(0x5b, 0), Point(0, -0x59), Point(-0x60, 0)),
                Diagonal(Point(0x40, 0x49), Point(0x42, -0x3e), Point(-0x46, -0x3c), Point(-0x4a, 0x4c))
            ),
            Maximum(
                Origin(Point(0, 0x4f), Point(0x4f, 0), Point(0, -0x56), Point(-0x57, 0)),
                Diagonal(Point(0x35, 0x34), Point(0x37, -0x3a), Point(-0x3f, -0x38), Point(-0x3e, 0x37))
            ),
        ],

        # Sammy Keyboard Controller
        # Brand-new.
        #[
        #    Maximum(
        #        Origin(Point(0, 0x5d), Point(0x5c, 0), Point(0, -0x5b), Point(-0x5e, 0)),
        #        Diagonal(Point(0x43, 0x41), Point(0x41, -0x3e), Point(-0x42, -0x3d), Point(-0x47, 0x43))
        #    ),
        #    Maximum(
        #        Origin(Point(0, 0x4e), Point(0x49, 0), Point(0, -0x50), Point(-0x5a, 0)),
        #        Diagonal(Point(0x33, 0x39), Point(0x34, -0x35), Point(-0x3c, -0x37), Point(-0x40, 0x34))
        #    ),
        #],
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

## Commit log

2004-08-06 Move cube64 into wasabi/devices, it seems to be the trendy place to be these days
    [cube64-basic.sch, cube64-mini.sch]
2011-03-26 cube64.asm: -Added support for identify command 0xFF. (Fixed issue #2) -Added support for 12F683 micro.
    Makefile:
    -Added support for 12F683 micro.
    n64gc_comm.inc:
    -Added support for identify command 0xFF. (Fixed issue #2)
    -Fixed typo about n64/ngc serial format.
    [cube64.asm]
2011-03-27 cube64.asm: -No GPR mirror in bank 1 for 12F683. So need to switch back to Bank 0 before any variables read. (Fixed issue #6)
    [cube64.asm]
2011-03-29 cube64.asm: -Added support for Wavebird (Enhancement #5 done) -Skip rumble update when in mode "slot empty"
    [cube64.asm]
2011-04-02 cube64.asm: -GameCube axis range ~[24, 232] now correctly translated into N64 axis range ~[-84, 84]. (Fixed issue #7)
    [cube64.asm]
2011-04-13 cube64.asm: -Modified Wavebird initialization to support different unique id. (Fixed issue #9)
    [cube64.asm]
2011-04-13 cube64.asm: -Their where not any n64_status_buffer initialization when a Wavebird receiver is not associated with a WB. Added n64_status_buffer initialization at the beginning. (Fixed issue #8)
    [cube64.asm]
2011-04-13 cube64.asm: -Better fix of n64_status_buffer bug with Wavebird, always clear buffer before calling n64_wait_for_command. -When a Wavebird is connected to the adapter, Cube64-DX now report to the n64 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
    [cube64.asm]
2011-04-14 cube64.asm: -Now EEPROM reset combo only affect the current active button mapping layout.
    [cube64.asm]
2011-04-15 Added schematic for PIC12F683
    [cube64-dx.sch]
2011-04-17 cube64.asm: -Fixed a bug with 16F84A EEPROM introduced by multi layout feature in 12F683 version.
    [cube64.asm]
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2011-04-20 Removed support for older microcontroller.
    cube64.asm:
    -Added a deadzone to the GC joystick to fix some issue with Wavebird.
    [cube64.asm]
2011-04-22 cube64.asm: -Removed n64_id_buffer overlap with gamecube_buffer. Allow to avoid saving WB UID into another RAM space. It was overwriten by n64_id_buffer previously. n64_id_buffer has now is own RAM s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
    [cube64.asm]
2011-05-08 cube64.asm: -Implemented new key combo handling method. All option are accessed now via a config menu (Accessed by pressing AL+AR+Start). Once in the menu you can enter remap function by pressing Sta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
    Their is two submenu currently. The adapter mode submenu is accessed by pressing D-pad UP while the button layout submenu is accessed by pressing D-pad LEFT.
    In adapter mode submenu pressing UP make the adapter show as controller with empty slot while pressing LEFT make it show as controller with Rumble Pak.
    In layout selection submenu, each D-pad direction select one of the 4 button mapping layout.
2018-01-04 Default serial bridge to normal polarity and script to /dev/ttyUSB0
    For use with FTDI TL-232R-3V3 cable.
2018-01-04 Script for polling N64/GC SI bus devices
    This script uses the serial bridge and pool in loops
    for the buttons status.
    It currently supports N64 controllers, N64 mouses & GameCube controllers.
2018-01-04 Rumble Pak is init by writing 0x80s at 0x8001
    Revise documentation base on serial bridge tests
    and logic analyzer observations with Majora's Mask.
    This didn't affect the adapter since the 32 bytes values
    are ignored.
    [bus.py]
2018-01-04 New firmware version running on PIC18F14K22 @ 64 MHz
    Port Cube64 from PIC12F683 @ 20 MHz to PIC18F14K22 @ 64 MHz.
    The speed increase will allow computing the CRC.
    [cube64-basic.sch, cube64-dx.sch, cube64-mini.sch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]
2018-01-04 Add realtime CRC computation base on the large table
    This fix Banjo-Kazooie & GoldenEye 007 Rumble Pak mode (Issue #1)
    [crc.py, crc_test.py, cube64.asm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]
2018-01-04 N64 bus read now receive the 2 address bytes
    If the address is 0x8001 we answer with a packet of 0x80s.
    Otherwise send 0x00s.
    This make us answer a bit slower (~14 μs) than before (~10 μs) but
    the N64 gonna wait for us up to 80 μs base on my tests.
2018-01-04 Make EEPROM mapping more versatile
    Will allow additional axes & buttons to be remapped.
2018-01-04 Split out signing and dead zone from axis mapping
    Move it to its own macro run right after the axis calibration.
    Also adjust axis->button mapping macro since value is now signed.
2018-01-04 Overhaul axes and buttons remapping
    Allow axis direction to be mappped just like button.
2018-01-04 Allow GC analog trigger to be map N64 axis & button
    The digital trigger buttons can still be set independently.
    As a side effect, however, it requires pressing the trigger real fast to
    set a digital trigger as a mapping destination.
2018-01-04 Add function to modify mapping layout with a button press
    Pressing the Y button at the top level menu will allow
    mapping a special function to the source button.
    The destination consists of one of the 4 D-pad directions who
    correspond respectively to one of the mapping layouts.
    While holding a button set to this function, the current
    mapping layout configured will be overwritten until
    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
2018-01-04 Make virtual buttons definitions more future proof
    That should allow changing the front end to any modern controllers.
2018-01-04 Add second config byte in EEPROM for each virtual buttons
    Required for future features.
2018-01-04 Use TMR0 for rumble feedback time base
    Using system polling rate could often result in rumble to be too short to be felt.
    This provides a consistent 250 ms rumble feedback.
    [cube64.asm]
2018-01-04 Allow selecting either digital or analog triggers for mapping
    By default button remap and special function combos will map to
    digital trigger buttons only.
    Pressing X in the main menu before either Start or Y will enable
    mapping to the analog trigger axes.
2018-02-06 Add bypass mode for using N64 controller as accessory slot
    Fixes #10
    The adaptor can now have a N64 controller attach to it on RA2 to be
    used as an accessory slot. Once in this mode the adaptor will only
    answer the button status commands. All other commands will be copied to
    the N64 controller. Then the controller response is copied back to the
    system.
    Pressing D-pad Up in the adaptor mode submenu (or at boot) will activate
    the function. Pressing D-pad Left or Right will either resume Rumble
    emulation or display the adaptor slot as empty.
    When toggling between mode, the adaptor will observe a 1 s period
    where it will show the slot as empty. This will force the games to
    re-identify the acce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
    [cube64.sch]
2018-02-06 Port Python 2 scripts to Python 3
    Use pySerial for serial bridge communication.
    Convert string usage to bytes.
    Fix prints and sorts.
    [addr_encoder.py, address_map.py, bus.py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]
2018-02-06 GameCube joysticks scaling
    Fixes #7
    GameCube joysticks range differs from the N64. N64 has a maximum of ~84 along the axes origin
    and ~71 in the diagonals. GameCube main joystick has a maximum (once dead zone & sign applied)
    of ~90 and ~65 for the same. C joystick maximums are a bit lower at ~82 and ~57. N64 max value
    once plot will give us a square-ish equilateral hexagon while GameCube is an equiangular &
    equilateral hexagon.
    This may be problematic in some games where the diagonal max speed could be lower. In other games
    the joystick may feel too sensitive since the main GC joystick output values are significantly
    higher along the origin.
    This feature uses the opposite axis as a referen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
    [controller_data.py, cube64.asm, gen_asm_js_scale.py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]
2018-06-01 Switch N64 system pin to PORTB
    Required for interrupt to work well.
    [cube64.sch]
2018-06-01 Split joystick scaling on/off switch on two buttons
    Easier to tell if it's on or off.
2018-06-01 Switch to banked access
    Will need to use the access mode for literal offset addressing later.
2018-06-01 Process N64 commands with interrupt
    The original design of Cube64 is base around the polling done
    by the host system. The adaptor will block waiting for a command
    from the N64. Once a command is received and answer then the adaptor
    does its business hoping to get back blocking for commands in time.
    This change make polling the GC controller the first thing done right after
    we finish processing an N64 command. That means the button status we
    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
2018-06-06 Support 1 player 2 controllers control style
    GoldenEye and Perfect Dark got a control style using
    two controllers as a way to get dual analog sticks.
    Since the adaptor is now interrupt base it's quite easy now
    to answer another poll on another pin.
    This duplicate the mapping of the C buttons (as analog) and R buttons into
    second set of buffers for the second controller.
    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
    [cube64.sch]
2018-06-21 Add LED to indicate we are in the menu
    [cube64.sch]
2018-06-21 Move 2nd controller pin to PORTB6
    Let's not overlap with the UART RX pin.
    [cube64.sch]
2018-07-07 Restore RA4 transition detection in serial bridge
    Somehow the published version from 2004 do not check for
    transition on RA4, it rather sent TMR0 value.
    Fix up as well couple Python 3 script issue.
    It's purely academic but it allows recreating Micah original
    experiment from 2004!
    Traces done with the serial bridge on the controller bus are
    in the ctrl_bus_trace folder.
    [address_map.py, serial_bridge.asm]
2018-10-06 Menu cleanup
    Renamed all labels to make clearer at which level of the menu
    they are used.
    Also moved the flags that control the transition between menu level
    to its own variable: atomic_flag. Any multiple bit change carried on this
    variable need to be done in an atomic operation. This avoids the interrupt
    placing the firmware in an invalid state.
    Other flags shouldn't require any particular handling.
    [cube64.asm]
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2018-10-06 Cleanup IOs & fixup bank bits
    Enable weak pull up on all 4 SI pin.
    Set unused pin to output low.
    No longer need to check if the 2nd controller port is plugin at
    boot to enable interrupt. The weak pull up will prevent
    triggering the interrupt.
    Remove PORTC debug.
    Setup UART TX at 115200 baud.
    Fixup a few n64gc_comm bank bits.
    [cube64.asm]
2018-10-06 Turbo buttons feature
    Using special function menu any GC button or axis can be set to one of
    3 turbo speed:
    C-Up: No turbo
    C-Left: Faster turbo: 1 frame set, 1 frame clear.
    C-Right: Medium turbo: 2 frame set, 2 frame clear.
    C-Down: Slower turbo: 2 frame set, 14 frame clear.
    Turbo needs to be set after mapping is set.
    Changing mapping will reset turbo configuration.
    [cube64.asm]
2018-10-06 EEPROM init hardening
    Observed some glitch in EEPROM init sometimes.
    Move interrupt handling out of the EEPROM reset function.
    Revalidate EEPROM after init.
    Also fixup unneeded double init of the first layout bank.
    [cube64.asm]
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2018-10-17 KiCad PCB design for Q10 mcu
    [cube64.kicad_pcb, cube64.sch, cube64_bom.csv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]
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2018-11-19 Allow in GoldenEye to shoot/switch weapon in the cut-scene via 2nd CTRL
    This is a speed run trick that requires two changes in the
    1 player 2 controllers feature:
    1. A new special button that can be mapped via X in the special
    feature menu. When pressed, this special button will mute the
    buttons reported to the first controller slot (Exept Z & Start).
    Without the mute the press on the 1st controller would skip the cut scene.
    2. A & B button press is added to the 2nd controller slot
    status. This allows to switch weapons.
    [cube64.asm]
